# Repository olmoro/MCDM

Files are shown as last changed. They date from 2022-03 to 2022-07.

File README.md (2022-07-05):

### <p align="center">MCDM - Moro Charge and Discharge Module
***
#### <p align="center"> Как это работает.
Зарядное устройство состоит из трех блоков.
Первый из них блок питания на 18 вольт соответствующей мощности, например [WX-DC2406](https://aliexpress.ru/item/1005001714079538.html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) настроенный на выходное напряжение 18 вольт.

Второй блок - плата управления на микроконтроллере ESP-WROOM-32D - дисплей, кнопки, светодиодная индикация, USB интерфейс. Назначение - ввод-вывод пользовательских настроек, исполнение выбранного алгоритма работы, логирование и управление по каналу WiFi. Данные об этом блоке в своем депозитории.
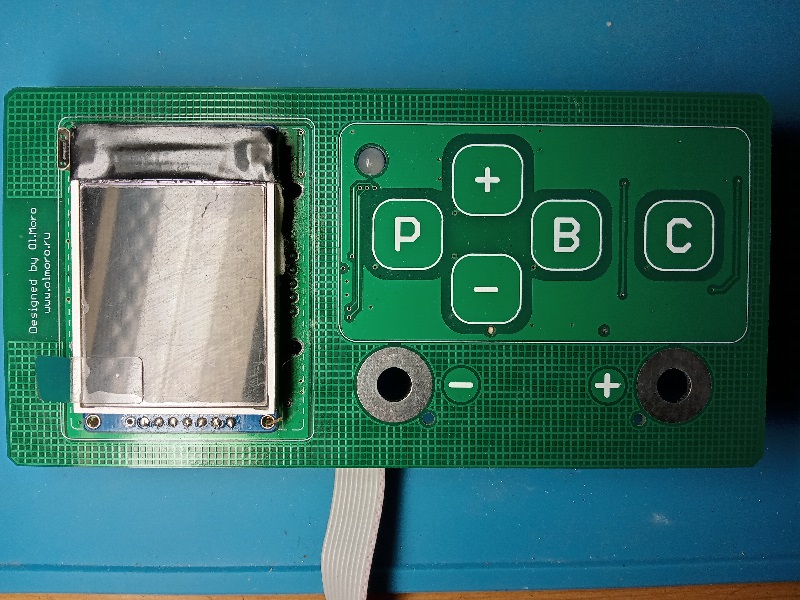
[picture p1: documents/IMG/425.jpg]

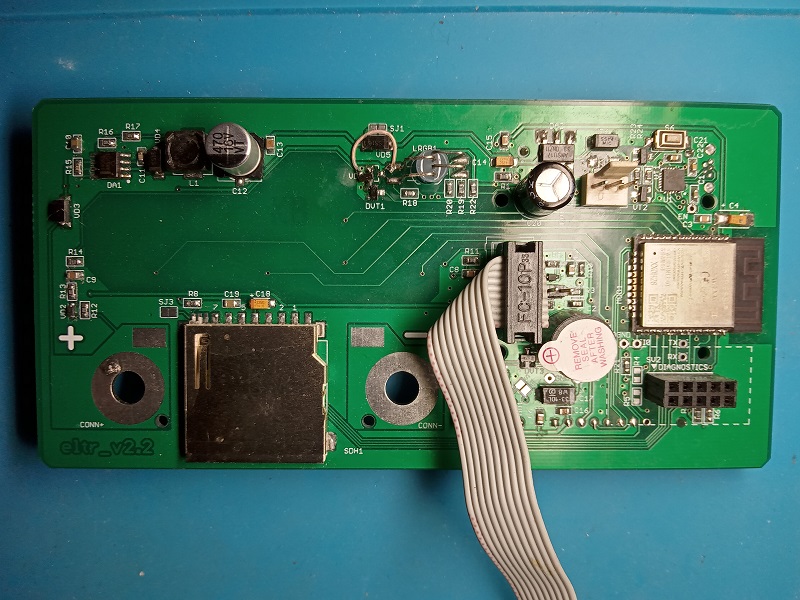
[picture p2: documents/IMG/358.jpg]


Третий блок - зарядно-разрядный модуль. Силовая часть заимствована от [XL4016 DC-DC Max 9A 300W](https://aliexpress.ru/item/32661166685.html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). Что от него осталось в итоге.
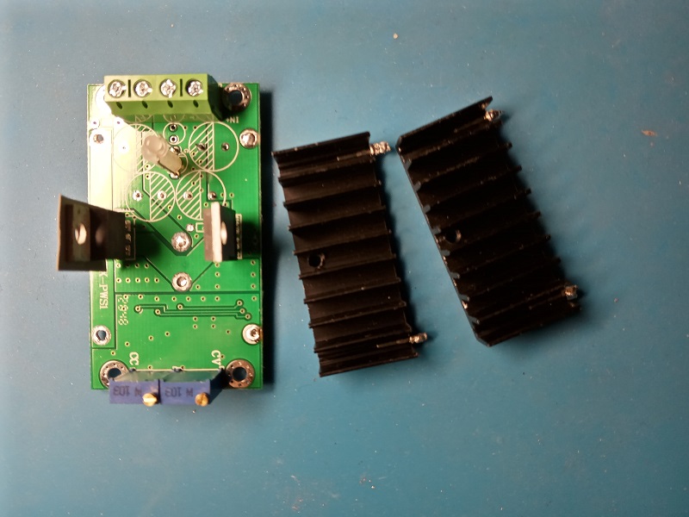
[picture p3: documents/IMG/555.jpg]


 Управляется субмодулем [WeMos D1 SAMD21 M0 Mini](https://aliexpress.ru/item/4001074203011.html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).
Субмодуль микроконтроллера съемный, устанавливается на гиперболические [разъемы](https://aliexpress.ru/item/32358969925.html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). Для работы с выходными ключами и питания субмодуля используются гальванически развязанные [источники](https://aliexpress.ru/item/1005003568781579.html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) мощностью 1 ватт. В свою очередь управляющие команды субмодуль получает по асинхронному интерфейсу от платы управления.
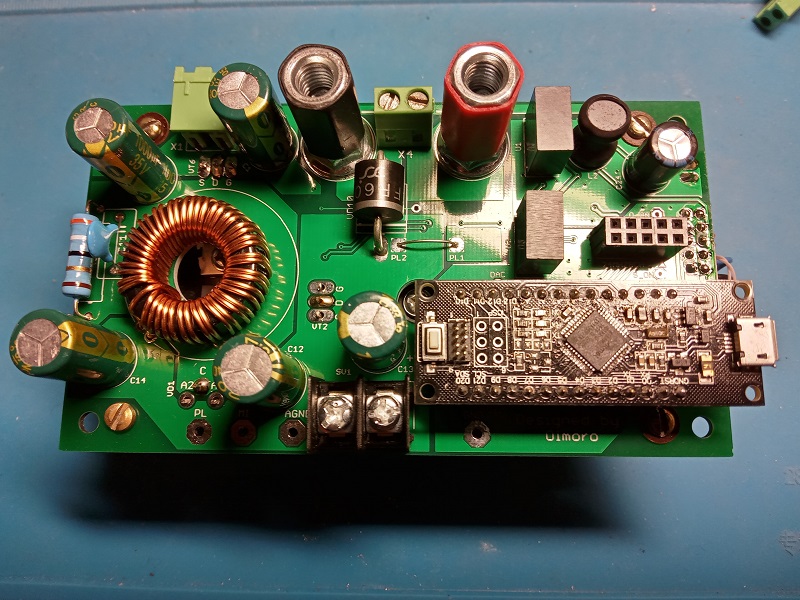
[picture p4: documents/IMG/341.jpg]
 Не отмыта пока.
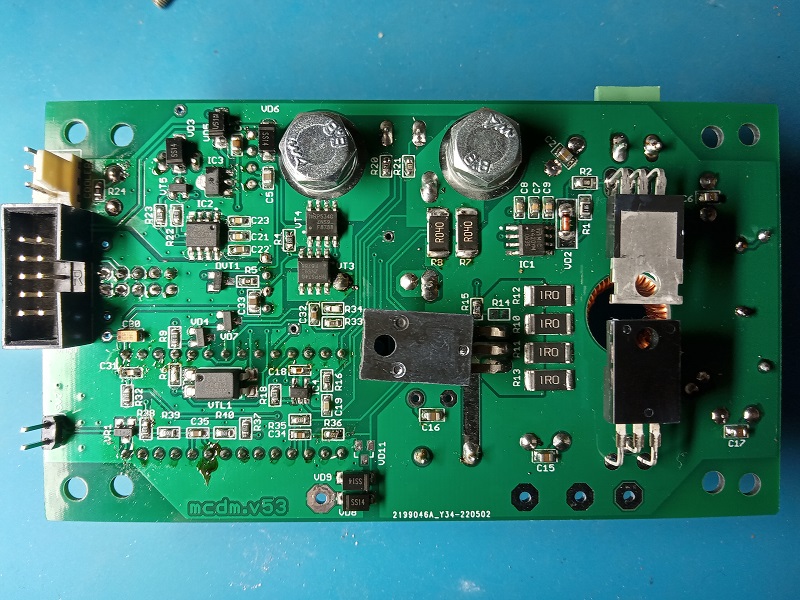
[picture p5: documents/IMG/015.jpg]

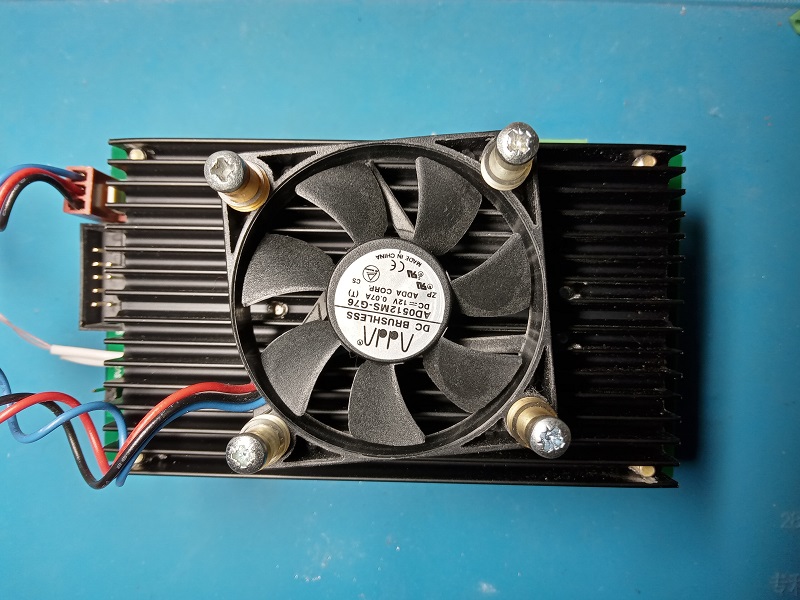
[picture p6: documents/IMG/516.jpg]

На блоке есть разъем для подключения 8-канального [логического анализатора](https://aliexpress.ru/item/4000183609972.html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).

#### <p align="center">Измерение напряжения
Измерение напряжения на подключенной батарее производятся по 4-х контактной схеме, используя дифференциальное измерение в диапазоне от -1.5 до 20 вольт. Погрешность измерения __% ± __ед.мзр.

#### <p align="center">Измерение токов заряда и разряда
Измерение токов заряда и разряда производится одним шунтом, используется сдвиг по напряжению для возможности измерения токов разной полярности в диапазоне от -5 до +10 ампер (ограничивается мощностью блока питания).  Погрешность измерения __% ± __ед.мзр.

#### <p align="center">Управление разрядной схемой
Ток разряда задается 10-разрядным встроенным ЦАП с поддержанием тока ПИД-регулятором. Схема разряда заимствована от Кулона 912, ток задается выходом DAC микроконтроллера. Внешним ОУ диапазон выходного сигнала расширен до 5 вольт. Для облегчения теплового режима регулирующего MOSFET предусмотрен разъем подключения внешней нагрузки.

#### <p align="center">Управление выходными ключами
Для реализации безискрового подключения заряжаемой батареи ключевой каскад управляется синхронно с силовым преобразователем, а именно: при отключении, например при перегрузке, одновременно отключается и силовой преобразователь. Остаточный заряд снимается подключением разрядной цепи (этот ток не проходит через токоизмерительный шунт). То есть включение преобразователя без подключения измерителя и на ХХ невозможно. Имеется возможность нагружать преобразователь при работе на холостом ходу или незначительной нагрузке.

#### <p align="center">Регулирование мощности DC преобразователя.
Управление понижающим преобразователем производится ШИМ-сигналом частотой 190кГц посредством MIC4420. Для регулирования напряжения и токов используются ПИД-регуляторы. В режиме заряда или источника питания регуляторы напряжения и тока используют собственные настройки. Для монотонности и непрерывности выходной характеристики используется один и тот же экземпляр регулятора. Принцип переключения от поддержания тока к поддержанию напряжения и обратно соответствует аналоговому регулятору 912-го кулона. Коэффициенты допускается регулировать "на лету". Для реализации импульсных режимов предусмотрены сохранение и восстановление параметров регулирования, но задание временнЫх параметров (длительность импульсов, например) возлагается на главный контроллер. Регулирование ведется с фиксированной частотой 10 Гц. Все вычисления целочисленные, так что вычисление шага занимает лишь несколько микросекунд. С этой целью параметры управления драйверу передаются предвычисленными и целочисленными.

#### <p align="center">Интерфейс
Обмен с главным контроллером производится по асинхронному каналу на частоте 115200 бод. Протокол обмена [WAKE](https://eewiki.ru/wiki/%D0%A1%D0%BF%D0%B5%D1%86%D0%B8%D1%84%D0%B8%D0%BA%D0%B0%D1%86%D0%B8%D1%8F_%D0%BF%D1%80%D0%BE%D1%82%D0%BE%D0%BA%D0%BE%D0%BB%D0%B0_WAKE) предусматривает проверку целостности пакета и подтверждение приема. Ведущим контроллером является главный контроллер, в фоновом режиме опрашивающий драйвер и получающий пакет, содержащий измерения напряжения в милливольтах и ток в миллиамперах, а также информацию о состоянии. Управляющими командами производится включение-отключение DC источника и задание напряжения и тока для ПИД-регулятора. Предусматривается достаточное количество команд настройки АЦП, приборного смещения, калибровочных коэффициентов для  преобразования в физические величины, порогов срабатывания защиты и т.д. Для управления и настройки ПИД-регулятора, и ещё масса тестовых команд, надобность в которых практически отпала по ходу дела. Заводские и пользовательские установки хранятся в памяти управляющего контроллера и загружаться на этапе инициализации, заменяя параметры разработчика (defaults).

В директории Frames представлены данные для тестирования с помощью приложения WakeUsb.

#### <p align="center">Система охлаждения
Силовые элементы, [датчик температуры](https://aliexpress.ru/item/33014111002.html?spm=a2g2w.productlist.0.0.108e2a96XiZTKA&sku_id=67175460751) и [вентилятор](https://aliexpress.ru/item/4001029238958.html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) размещены на [радиаторе](https://aliexpress.ru/item/1005003036398261.html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) размером 100x60x10 мм. Регулирование производится ПИД-регулятором.

#### <p align="center">Печатная плата
115*65 мм двусторонняя 1oz. Схема, сборки, перечень элементов и гербер-файлы в директории Docements.

#### <p align="center">Формат реализованных команд управления.
##### <p align="center">(Не отредактировано)
Имя | Код | Параметр | Ответ | Примечание
--------------------------:|------:|-------:|-------------:|----------------------------------:
cmd_read_u_i|0x10|-|int int uint|Чтение напряжения,тока (мВ и мА) и состояния
cmd_get_u|0x11|-|int|Чтение напряжения (мВ)
cmd_get_i|0x12|-|int|Чтение тока (мА)
cmd_get_ui|0x13|-|int int|Чтение напряжения и тока (мВ и мА)
cmd_get_state|0x14|-|uint|Чтение состояния
cmd_get_state|0x15|-|uint|Чтение температуры радиатора
cmd_power_go|0x20|-|-|Старт преобразователя с заданными максимальными U и I
cmd_power_stop|0x21|-|-|Отключение ( и разряда в том числе)
cmd_set_pid|0x22|-|-|set all parameters (в разработке)
cmd_get_factor_u|0x30|-|uint|Чтение множителя преобразования в милливольты
cmd_set_factor_u|0x31|uint|-|Запись множителя преобразования в милливольты
cmd_set_factor_default_u|0x32|-|-|Возврат к заводскому множителю преобразования в милливольты
cmd_get_smooth_u|0x33|-|uint|Чтение параметра сглаживания по напряжению
cmd_set_smooth_u|0x34|uint|-|Запись параметра сглаживания по напряжению (1...3)
cmd_get_offset_u|0x35|-|uint|Чтение приборного смещения по напряжению
cmd_set_offset_u|0x36|int|-|Запись приборного смещения по напряжению
cmd_get_factor_i|0x38|-|uint|Чтение множителя преобразования в миллиамперы
cmd_set_factor_i|0x39|uint|-|Запись множителя преобразования в миллиамперы
cmd_set_factor_default_i|0x3A|-|-|Возврат к заводскому множителю преобразования в миллиамперы
cmd_get_smooth_i|0x3B|-|uint|Чтение параметра сглаживания по току
cmd_set_smooth_i|0x3C|uint|-|Запись параметра сглаживания по току (1...3)
cmd_get_offset_i|0x3D|-|uint|Чтение приборного смещения по току
cmd_set_offset_i|0x3E|int|-|Запись приборного смещения по току
cmd_pid_configure|0x40|uint uint uint uint uint uint|-|set mode,kp,ki,kd,min,max
cmd_pid_set_coefficients|0x41|uint uint uint|-|set kp, ki, kd
cmd_pid_output_range|0x42|uint uint|-|set min, max
cmd_pid_reconfigure|0x43|uint uint uint uint uint|-|set kp,ki,kd,min,max w/o clear
cmd_pid_clear|0x44|-|-|clear
cmd_pid_test|0x46|uint uint uint|-|mode, setpoint, sw
cmd_pid_get_configure|0x48|-|uint uint uint uint uint uint|mode,kP,kI,kD,min,max - возвращает параметры текущего режима регулирования
cmd_pid_set_max_sum|0x49|uint|-|Задает максимальный интеграл при вычислении шага рег.
cmd_set_cooler|0x4F|uint|-|Задать скорость вентилятора
cmd_adc_read_probes|0x50|-|int,int|Read all probes
cmd_adc_get_offset|0x51|-|int|Читать смещение АЦП
cmd_adc_set_offset|0x52|int|-|Запись смещения АЦП
cmd_set_switch_pin|0x54|?|-|sw_pin D4 PA14 ?
cmd_set_power|0x56|int|-|пользоваться с осторожностью - выяснение пределов регулирования
cmd_set_discharge|0x57|uint|-|не проверена
cmd_set_voltage|0x58|uint|-|старая, не проверена
cmd_set_current|0x59|uint|-|старая, не проверена
cmd_set_discurrent|0x5A|uint|-|старая, не проверена
cmd_set_surge_compensation|0x5B|?|-|параметры подавления всплеска напряжения na
cmd_set_idle_load|0x5C|uint|-|параметры доп.нагрузки ХХ
cmd_get_win_less_u|0x60|-|int|Порог отключения по Umin
cmd_set_win_less_u|0x61|int|-|Порог отключения по Umin
cmd_set_win_less_default_u|0x62|int|-|Порог отключения по Umin
cmd_get_win_up_u|0x63|-|int|Порог отключения по Umax
cmd_set_win_up_u|0x64|int|-|Порог отключения по Umax
cmd_set_win_up_default_u|0x65|int|-|Порог отключения по Umax
cmd_get_win_less_i|0x68|-|int|Порог отключения по Imin
cmd_set_win_less_i|0x69|int|-|Порог отключения по Imin
cmd_set_win_less_default_i|0x6A|int|-|Порог отключения по Imin
cmd_get_win_up_i|0x6B|-|int|Порог отключения по Imax
cmd_set_win_up_i|0x6C|int|-|Порог отключения по Imax  
cmd_set_win_up_default_i|0x6D|int|-|Порог отключения по Imax

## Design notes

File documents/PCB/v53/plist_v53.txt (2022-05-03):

Partlist

Exported from mcdm.v53.sch at 03.05.2022 9:25

EAGLE Version 7.3.0 Copyright (c) 1988-2015 CadSoft

Assembly variant: 

Part     Value          Device              Package       Library              Sheet

+5V                     WIREPAD1,6/0,8      1,6/0,8       wirepad              2
+18V                    WIREPAD1,6/0,8      1,6/0,8       wirepad              1
AGND     AGND           WIREPAD4,16O1,6     4,16O1,6      wirepad              2
C1       1000µF 35v     CPOL-EUE5-10.5      E5-10,5       rcl_moro             1
C2       100n           C-EUC0805           C0805         rcl_moro             1
C3       1000µF 35v     CPOL-EUE5-10.5      E5-10,5       rcl_moro             1
C4       4.7µF          C-EUC0603           C0603         rcl_moro             1
C5       4.7µF          C-EUC0603           C0603         rcl_moro             1
C6       100n           C-EUC0805           C0805         rcl_moro             1
C7       100n           C-EUC0603           C0603         rcl_moro             1
C8       1mkF           C-EUC0603           C0603         rcl_moro             1
C9       100n           C-EUC0603           C0603         rcl_moro             1
C11      4.7nF 1KV      C-EU102-064X133     C102-064X133  rcl_moro             1
C12      470µF 35v      CPOL-EUE5-10.5      E5-10,5       rcl_moro             1
C13      na             CPOL-EUE5-10.5      E5-10,5       rcl_moro             1
C14      470µF 35v      CPOL-EUE5-10.5      E5-10,5       rcl_moro             1
C15      1mkF           C-EUC0805           C0805         rcl_moro             1
C16      1mkF           C-EUC0805           C0805         rcl_moro             1
C17      1mkF           C-EUC0805           C0805         rcl_moro             1
C18      100nF X7R      C-EUC0603           C0603         rcl_moro             1
C19      1µF            C-EUC0603           C0603         rcl_moro             1
C21      100n           C-EUC0603           C0603         rcl_moro             1
C22      1mkF           C-EUC0603           C0603         rcl_moro             1
C23      100n           C-EUC0603           C0603         rcl_moro             1
C24      220uF 25v      CPOL-EUE5-8.5       E5-8,5        rcl_moro             1
C30      4.7µF          C-EUC0805           C0805         rcl_moro             2
C31      100nF X7R      C-EUC0603           C0603         rcl_moro             2
C32      470n           C-EUC0603           C0603         rcl_moro             2
C33      3.3µF          C-EUC0805           C0805         rcl_moro             2
C34      470nF          C-EUC0603           C0603         rcl_moro             2
C35      470nF          C-EUC0603           C0603         rcl_moro             2
COOLER   WF-3 (WF-2)    WF-3                WF-3          moro2                1
DAC                     WIREPAD1,6/0,8      1,6/0,8       wirepad              2
DVT1     PDTA123ET      MUN2113T1           SC59-BEC      transistor-pnp       1
GND      GND            WIREPAD4,16O1,6     4,16O1,6      wirepad              2
IC1      MIC4420M       MIC4420M            SO-08         transistor-power     1
IC2      MIC4420M       MIC4420M            SO-08         transistor-power     1
IC3      78L12F         78L12F              SOT89         linear               1
IC4      LMV321(MCP601) LM321MF             SOT23-5       linear               1
L1       L32MM          L32MM               L22MM         wx-d21               1
L2       560uH          BS11                BS11          inductor-neosid-moro 1
MI                      WIREPAD4,16O1,6     4,16O1,6      wirepad              1
OUT                     WIREPAD1,6/0,8      1,6/0,8       wirepad              2
O_ON                    WIREPAD1,6/0,8      1,6/0,8       wirepad              2
PL                      WIREPAD4,16O1,6     4,16O1,6      wirepad              1
PL1                     WIREPAD2,54/0,8     2,54/0,8      wirepad              1
PL2                     WIREPAD2,54/0,8     2,54/0,8      wirepad              1
R1       5R1            R-EU_R0805          R0805         rcl_moro             1
R2       1R             R-EU_R0805          R0805         rcl_moro             1
R3       39 Om 5%       R-0515/20           0515/20       Q921                 1
R4       2.2k           R-EU_R0603          R0603         rcl_moro             1
R5       330            R-EU_R0603          R0603         rcl_moro             1
R6       680            R-EU_R0603          R0603         rcl_moro             1
R7       R04            R-EU_R2512          R2512         rcl_moro             1
R8       R04            R-EU_R2512          R2512         rcl_moro             1
R9       100k           R-EU_R0603          R0603         rcl_moro             1
R10      1R0            R-EU_R2512          R2512         rcl_moro             1
R11      1R0            R-EU_R2512          R2512         rcl_moro             1
R12      1R0            R-EU_R2512          R2512         rcl_moro             1
R13      1R0            R-EU_R2512          R2512         rcl_moro             1
R14      na             R-EU_R0603          R0603         rcl_moro             1
R15      5k1            R-EU_R0603          R0603         rcl_moro             1
R16      5k1            R-EU_R0603          R0603         rcl_moro             1
R18      5k1            R-EU_R0603          R0603         rcl_moro             1
R20      22R            R-EU_R0603          R0603         rcl_moro             1
R21      22R            R-EU_R0603          R0603         rcl_moro             1
R22      100k           R-EU_R0603          R0603         rcl_moro             1
R23      51             R-EU_R0603          R0603         rcl_moro             1
R24      10k            R-EU_R0603          R0603         rcl_moro             1
R32      680            R-EU_R0603          R0603         rcl_moro             2
R33      39k0           R-EU_R0603          R0603         rcl_moro             2
R34      4k70           R-EU_R0603          R0603         rcl_moro             2
R35      22             R-EU_R0603          R0603         rcl_moro             2
R36      22             R-EU_R0603          R0603         rcl_moro             2
R37      4k7            R-EU_R0603          R0603         rcl_moro             2
R38      10k0           R-EU_R0603          R0603         rcl_moro             2
R39      30k            R-EU_R0603          R0603         rcl_moro             2
R40      30k            R-EU_R0603          R0603         rcl_moro             2
SV1      TB-10-2        TB-10-2             TB-10-2       wx-d21               1
SV2                     JP1Q                JP1           jumper_moro          2
SV4      FE05-2R        FE05-2R             FE05-2R       con-lsta_moro        2
S_ON                    WIREPAD1,6/0,8      1,6/0,8       wirepad              2
U1       HLK-1D1212     HLK-1D1212          HLK-1D1212    wx-d21               1
U2       B1205S-1W      HLK-1D1212          HLK-1D1212    wx-d21               2
UART     BH-10          ML10                ML10          con-harting-ml       2
VD1      MBR20100F      MBR20100F           ITO220J       wx-d21               1
VD2      4148           DIODESMA            SMADIODE      microbuilder         1
VD3      SS16           SS16                DO214AC       diode-1              1
VD4      BAT54S         BAT54S              SOT23         diode                2
VD5      US1M           US1M                DO214AC       diode-1              1
VD6      SS16           SS16                DO214AC       diode-1              1
VD7      BAT54S         BAT54S              SOT23         diode                2
VD8      SS16           SS16                DO214AC       diode-1              2
VD9      SS16           SS16                DO214AC       diode-1              2
VD10     FR601          DIODE-1_DIODE-P6-15 DIODE-1_P6-15 urc-2base            1
VD11     BAT54S         BAT54S              SOT23         diode                2
VR1      TL431          TL431-SOT23-3       SOT23         moro4                2
VT2      STP16NF06FP    STP16NF06FP         TO-220FP_M    wx-d21               1
VT3      IRF8788        IRF8788             SO-8          transistor-fet_moro  1
VT4      IRF8788        IRF8788             SO-8          transistor-fet_moro  1
VT5      IRLML5203      IRLML5203           MICRO3        transistor-power     1
VT6      IRFP9540N_M    IRFP9540N_M         TO-220FP_M    wx-d21               1
VTL1     K10104C        SFH618A-3X007       SMD4-7        optocoupler          1
X1       MSTBA2         MSTBA2              MSTBA2        con-phoenix-508      1
X2       BP-R           BP-R                BP-R          wx-d21               1
X3       BP-B           BP-B                BP-B          wx-d21               1
X4                      AK500/2-H           AK500/2-H     con-ptr500_moro      1
X5       F14GIP         F14GIP              F14GIP        wx-d21               2
X6       F14GIP         F14GIP              F14GIP        wx-d21               2

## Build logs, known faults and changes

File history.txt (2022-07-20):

.LOG

20:02 04.12.2021
После переустановки VS на Lenovo
MSAMD21 - полная копия MORO_D21 (DRV_BS4) MORO_D21_20210515full.zip - архив полный
Папка проекта F:\GitHub

14:57 09.12.2021
Добавлено
documents (Frames, Pid)

20:26 26.01.2022
Проект скопирован под новым именем MCDM: Измерительный модуль ЗУ с теплоотводом (Charge and discharge module)
Размер платы 100 * 65 мм.
Питание от внешнего источника 18 вольт 6 ампер.
Подключение батареи четырехточечное.
Интерфейс асинхронный 115200 Бод.
Выходной ток заряда до 10 ампер (измеряемый).
Входной ток заряда до 10 ампер (измеряемый).
Измерение выходного напряжения от -2 до 18 вольт.
Измерение тока от -10 до +10 ампер одним шунтом.
Пид-регулирование.

Будет добавлено управление системой охлаждения.

https://github.com/ocrdu/Arduino_SAMD21_turbo_PWM
  PWM Freg 192.0 kHz:
Main Clock Divider  1   5
TCCx Prescaler      1   1
Resolution          500 100

SAMD21G18 timer/channel:

TCC0/WO[0]: PA04, PA08         TCC0/WO[4]: PA14, PA22, PB10
TCC0/WO[1]: PA05, PA09         TCC0/WO[5]: PA15, PA23, PB11
TCC0/WO[2]: PA10, PA18         TCC0/WO[6]: PA12, PA16, PA20
TCC0/WO[3]: PA11, PA19         TCC0/WO[7]: PA13, PA17, PA21

TCC1/WO[0]: PA06, PA10, PA30   TCC1/WO[2]: PA08, PA24
TCC1/WO[1]: PA07, PA11, PA31   TCC1/WO[3]: PA09, PA25

TCC2/WO[0]: PA00, PA12, PA16
TCC2/WO[1]: PA01, PA13, PA17

20:26 07.03.2022
Для совместимости с SAMD21turboPWM.h
изменена схема подключения cool_pin и out_pin
TCC0/WO[2]: PA18(out)
TCC2/WO[0]: PA16(cool)

13:26 21.04.2022
Заменить эти файлы на одноименные из "documents/Variant"
C:\Users\olmor\.platformio\packages\framework-arduino-samd\variants\arduino_zero\variant.cpp
C:\Users\olmor\.platformio\packages\framework-arduino-samd\variants\arduino_zero\variant.h
C:\Users\olmor\.platformio\packages\framework-arduino-samd\cores\arduino\wiring_analog.c

9:29 03.05.2022
Заказано изготовление mcdm_v53
19:29 22.05.2022
маркировка R33, R34 переставлена. Откорректировано в v53a.
Добавлены резисторы защиты по 7,5кОм
19:50 28.05.2022
Увеличена скорость обмена до 230400
10:29 03.07.2022
Версия 0.1 с пид-регуляторами

// param_shift увеличен с 8 до 12; param_max = 0x000F, param_mult = 0x1000
RAM:   [=         ]  12.7% (used 4176 bytes from 32768 bytes)
Flash: [=         ]   9.2% (used 24228 bytes from 262144 bytes)

04.07.2022
Новые модули на COM13 и COM14 (Arduino Zero 1.4.3.0) проверены

05.07.2022
Отказ от эмуляции EEPROM. Заводские и пользовательские установки
будут храниться в памяти управляющего контроллера и загружаться
на этапе инициализации, заменяя параметры разработчика (defaults) 
RAM:   [=         ]   9.5% (used 3120 bytes from 32768 bytes)
Flash: [=         ]   8.7% (used 22692 bytes from 262144 bytes)

14.07
COM14 - OK
RAM:   [=         ]   9.5% (used 3120 bytes from 32768 bytes)
Flash: [=         ]   8.7% (used 22720 bytes from 262144 bytes)

19.07
Новая команда 0x47 отдает paramMult
RAM:   [=         ]   9.5% (used 3120 bytes from 32768 bytes)
Flash: [=         ]   8.7% (used 22784 bytes from 262144 bytes)

20.07
RAM:   [=         ]   9.5% (used 3120 bytes from 32768 bytes)
Flash: [=         ]   8.7% (used 22780 bytes from 262144 bytes)

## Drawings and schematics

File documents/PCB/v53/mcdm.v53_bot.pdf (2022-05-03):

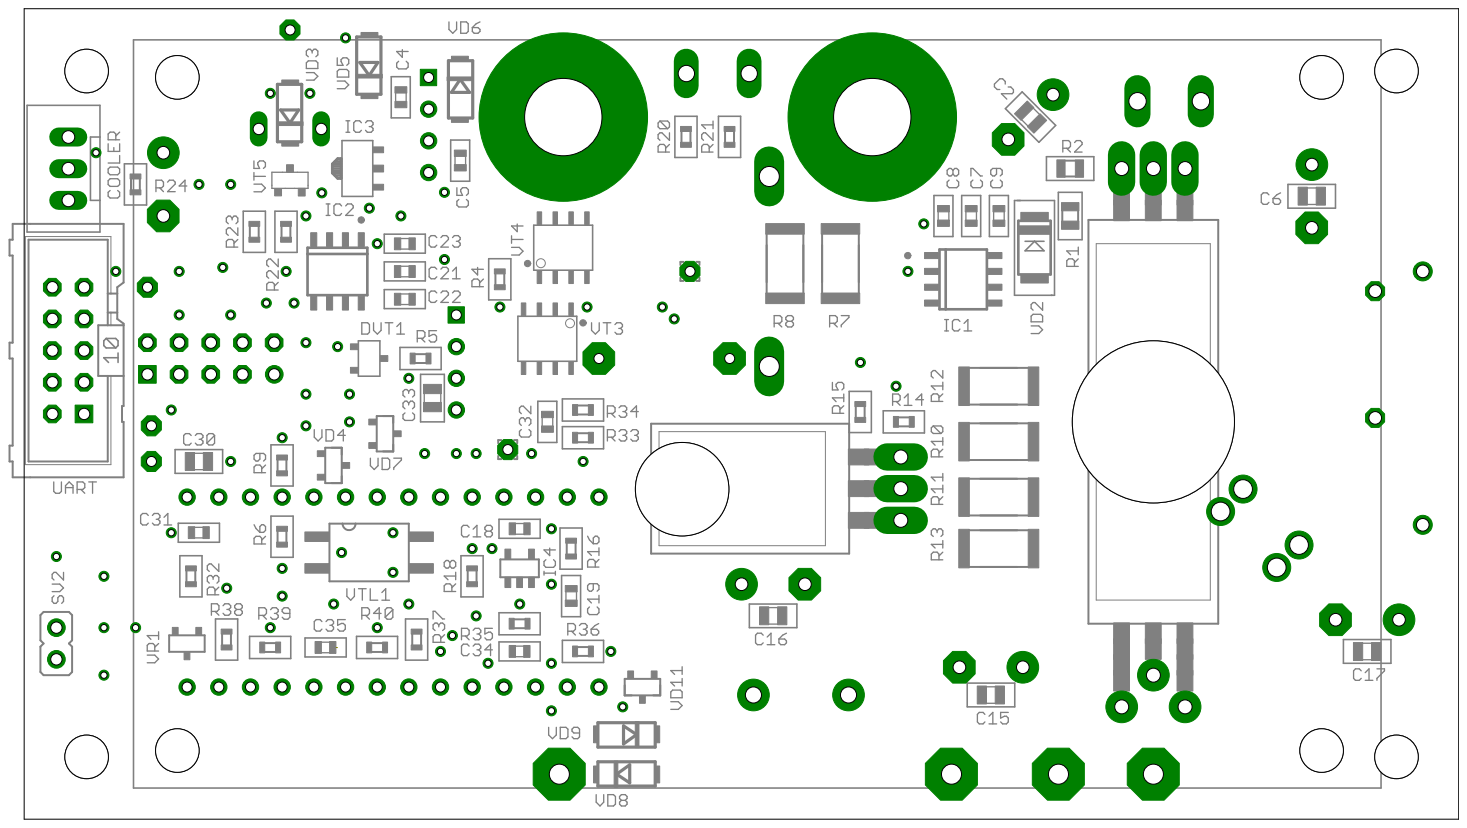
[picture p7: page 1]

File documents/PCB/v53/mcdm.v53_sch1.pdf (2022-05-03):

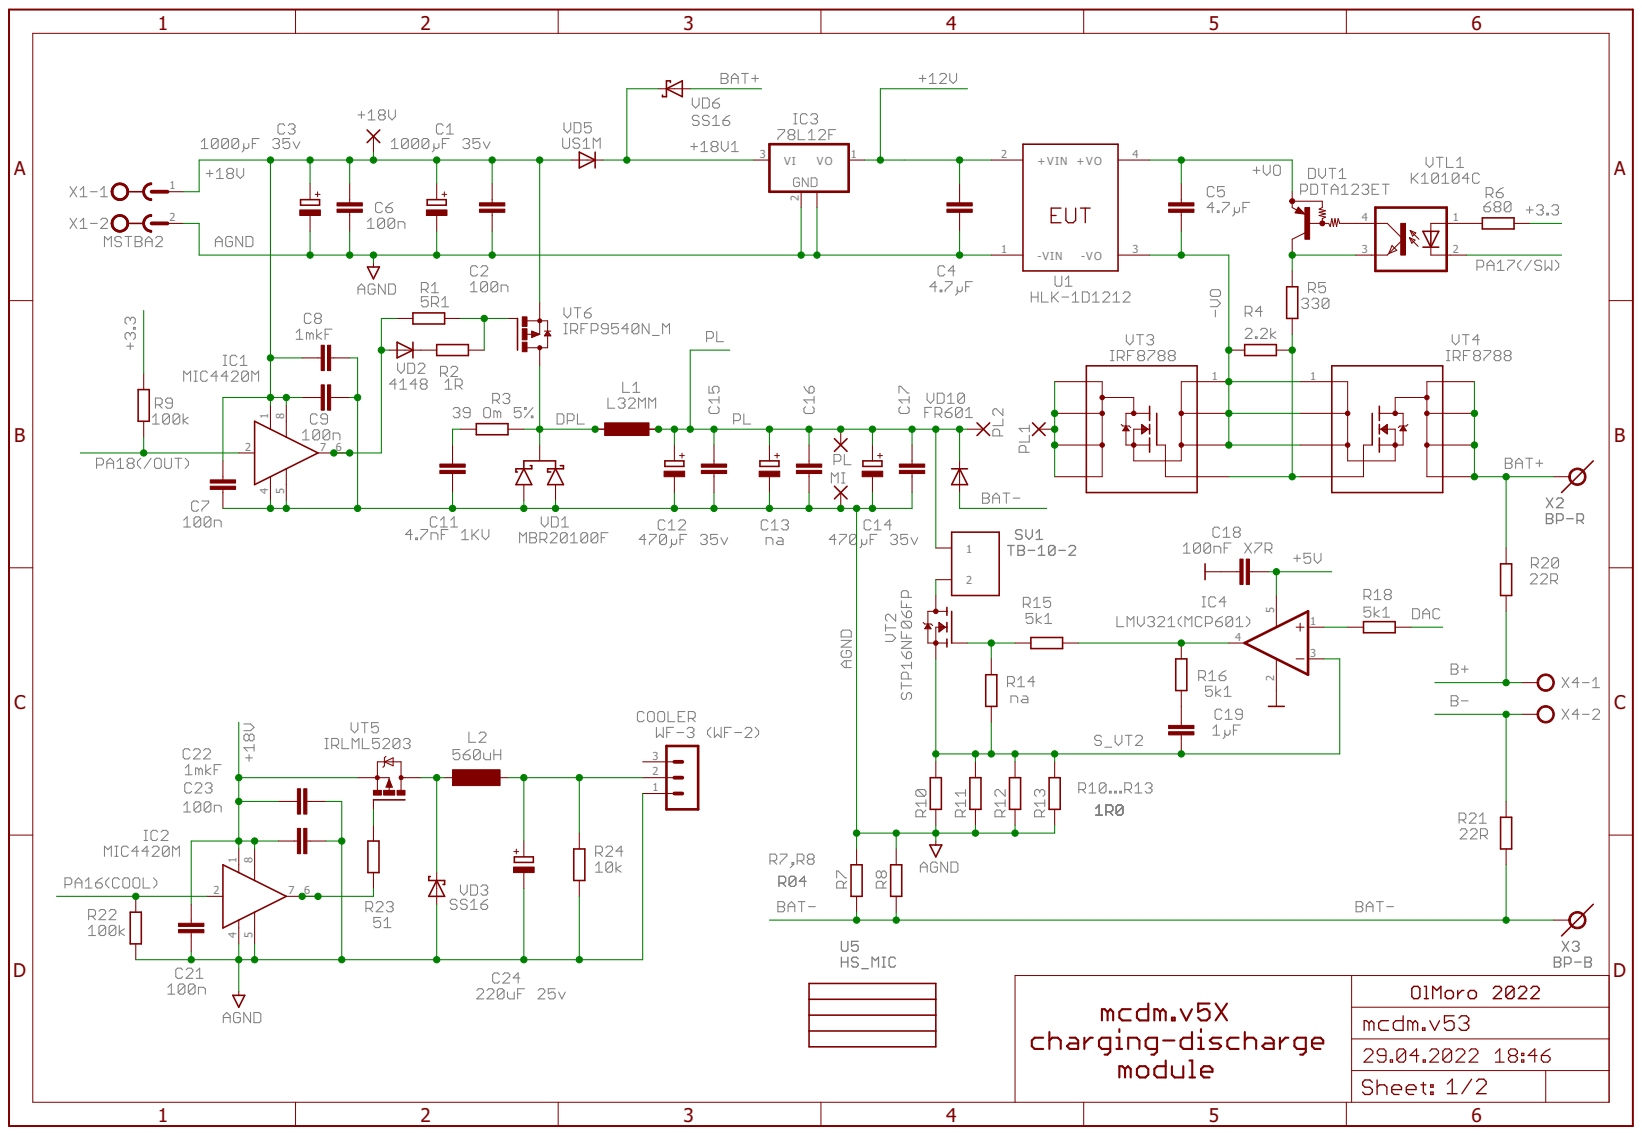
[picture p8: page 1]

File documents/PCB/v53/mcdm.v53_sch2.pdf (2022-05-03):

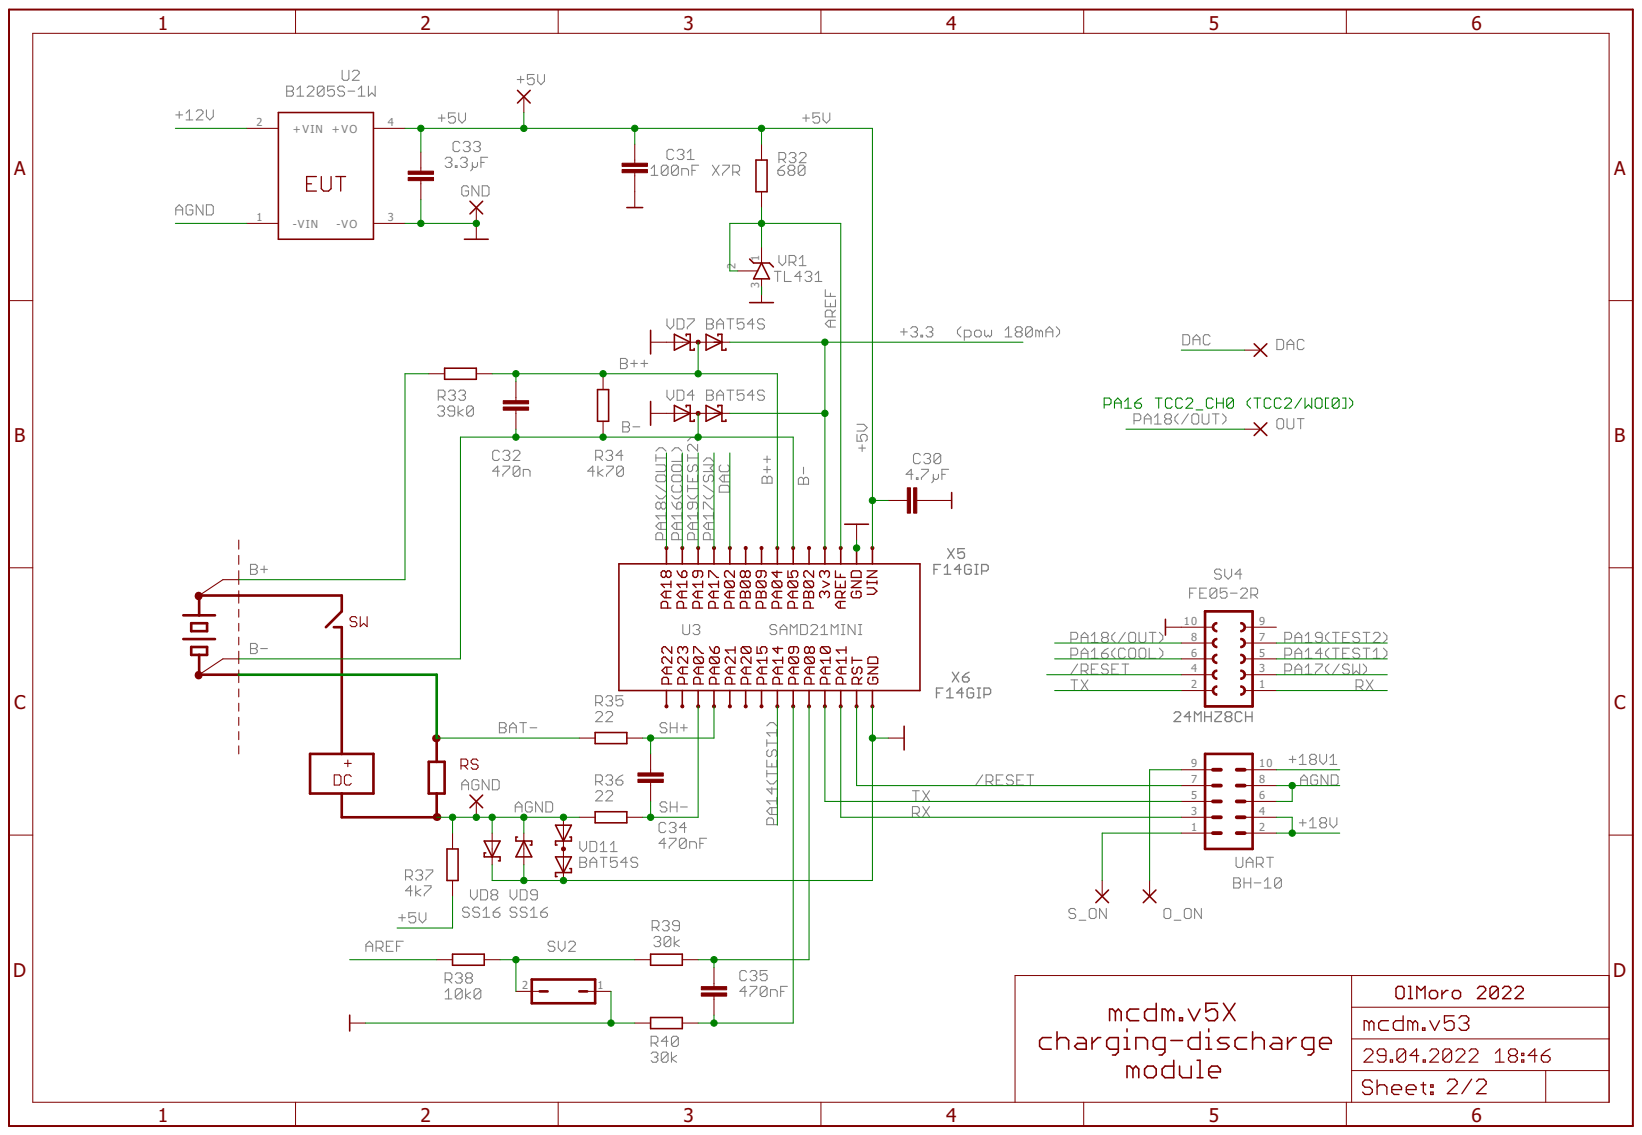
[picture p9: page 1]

1 2 3 975 1086 31 421 2 3 4 5 6 7 8 9 10 -VIN 1 +VIN 2 +VO 4 -VO 3 2 1 ABCD 1 2 3 4 5 6 ABCD 1 2 3 4 5 6

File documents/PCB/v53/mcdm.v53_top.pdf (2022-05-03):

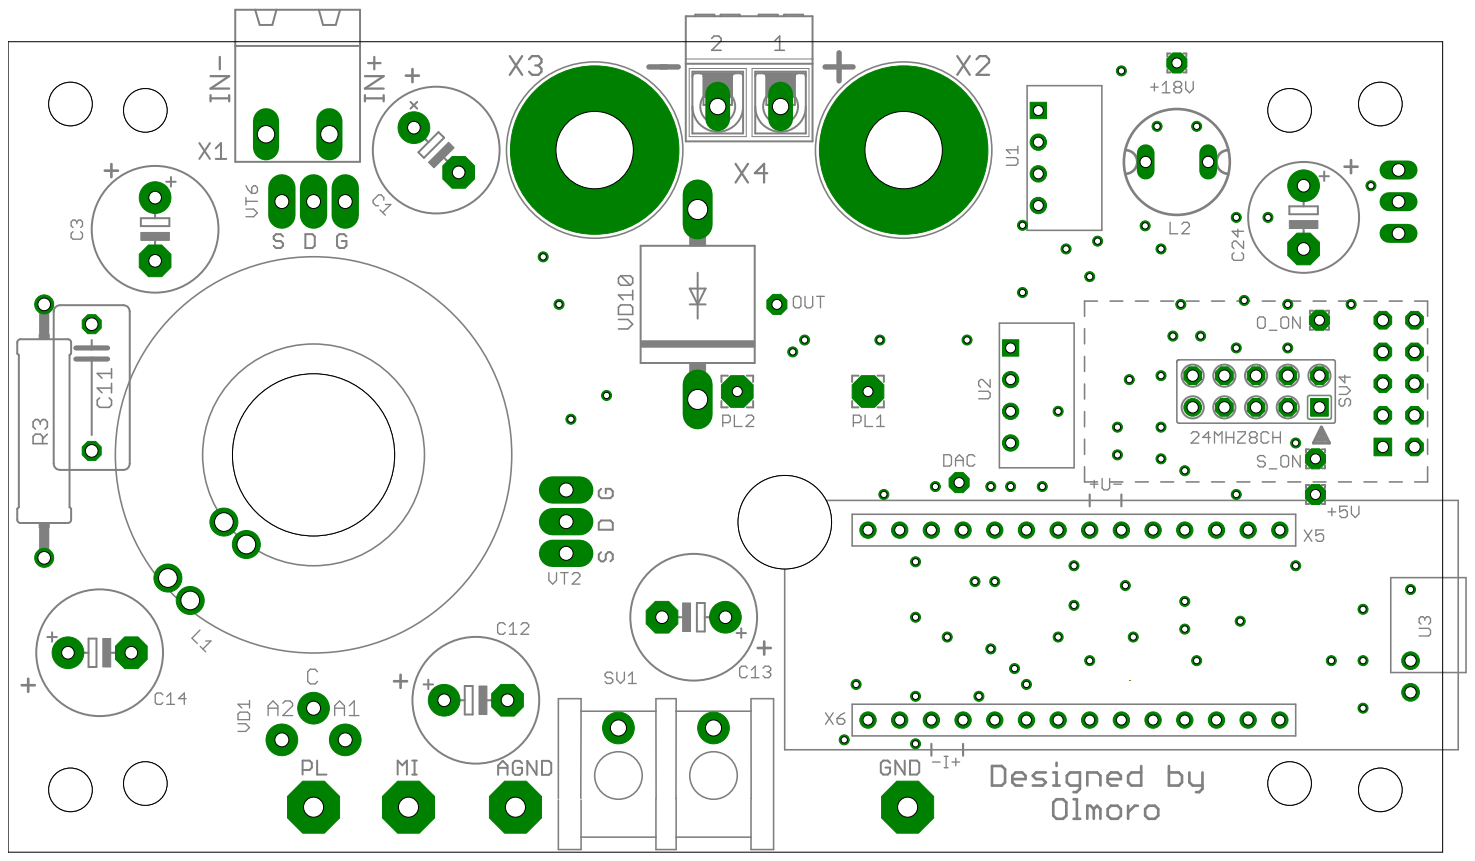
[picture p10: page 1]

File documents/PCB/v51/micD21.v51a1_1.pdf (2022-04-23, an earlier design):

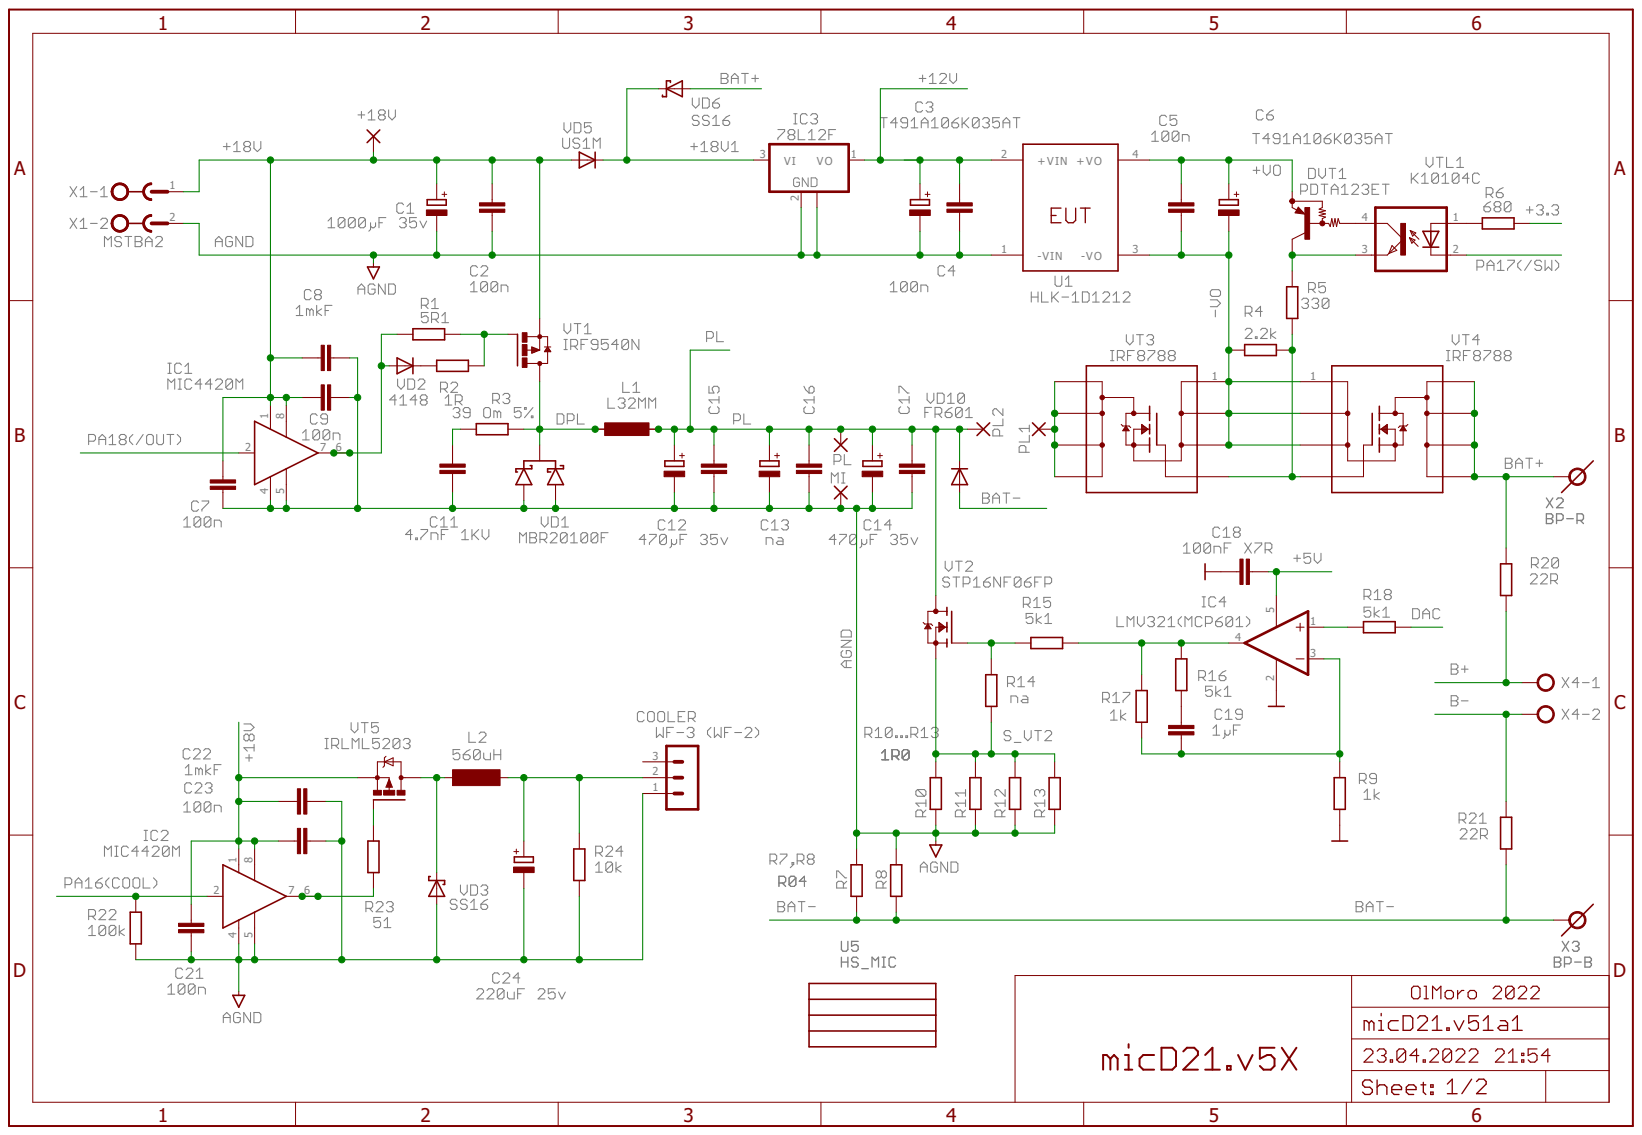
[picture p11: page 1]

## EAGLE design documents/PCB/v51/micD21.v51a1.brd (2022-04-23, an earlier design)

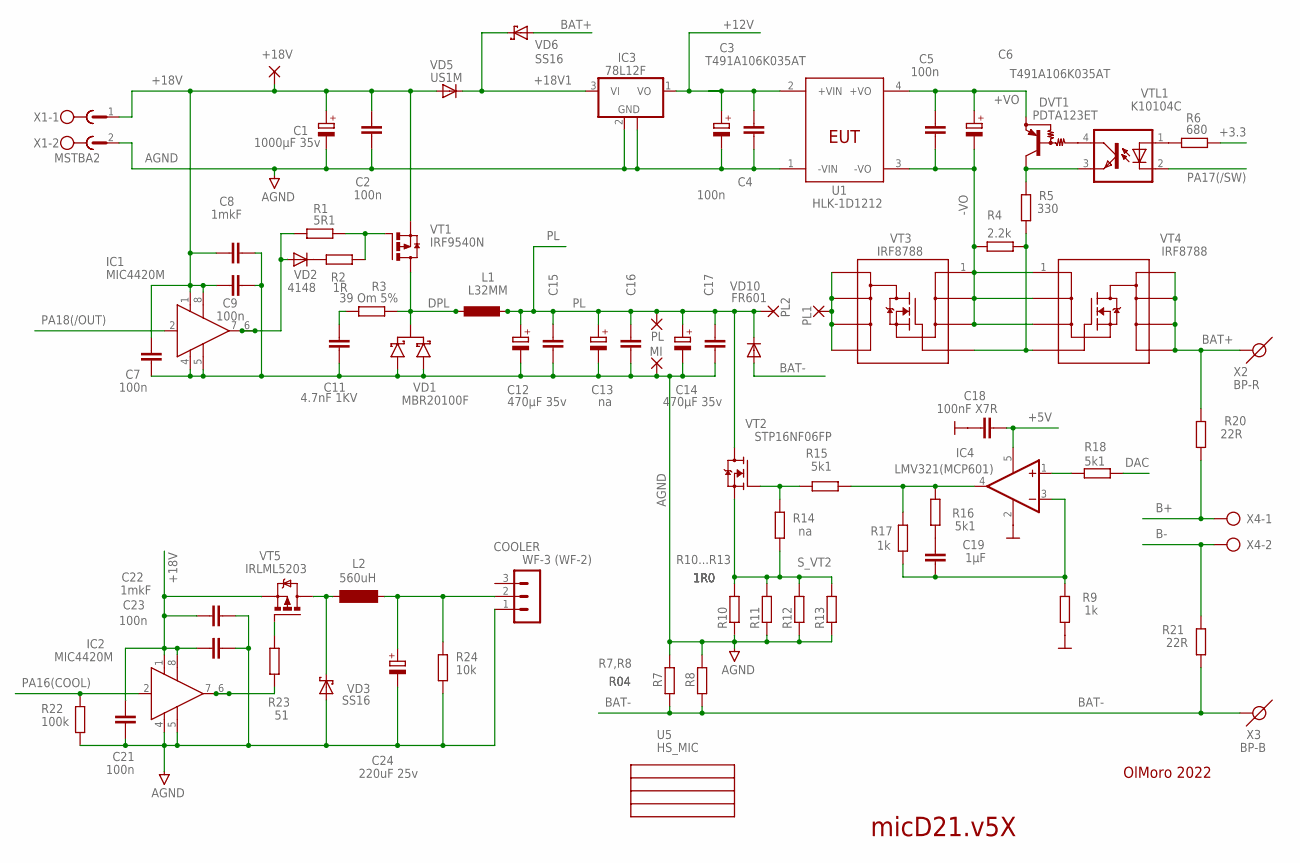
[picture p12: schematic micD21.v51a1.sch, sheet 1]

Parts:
+18V: WIREPAD1,6/0,8; 1,6/0,8
C1: 1000µF 35v; E5-10,5
C2: 100n; C0805
C3, C6: T491A106K035AT; CT3528
C4, C5, C7, C9, C21, C23: 100n; C0603
C8, C22: 1mkF; C0603
C11: 4.7nF 1KV; C102-064X133
C12, C14: 470µF 35v; E5-10,5
C13: na; E5-13
C15, C16, C17: 1mkF; C0805
C18: 100nF X7R; C0603
C19: 1µF; C0603
C24: 220uF 25v; E5-8,5
COOLER: WF-3 (WF-2); WF-3
DVT1: PDTA123ET; SC59-BEC
IC1, IC2: MIC4420M; SO-08
IC3: 78L12F; SOT89
IC4: LMV321(MCP601); SOT23-5
L1: L32MM; L22MM
L2: 560uH; BS11
MI: 4,16O1,6
PL: 4,16O1,6
PL1, PL2: 2,54/0,8
R1: 5R1; R0805
R2: 1R; R0805
R3: 39 Om 5%; 0515/20
R4: 2.2k; R0603
R5: 330; R0603
R6: 680; R0603
R7, R8: R04; R2512
R9, R17: 1k; R0603
R10, R11, R12, R13: 1R0; R2512
R14: na; R0603
R15, R16, R18: 5k1; R0603
R20, R21: 22R; R0603
R22: 100k; R0603
R23: 51; R0603
R24: 10k; R0603
U1: HLK-1D1212
U5: HS_MIC; HS-MIC
VD1: MBR20100F; ITO220J
VD2: 4148; SMADIODE
VD3, VD6: SS16; DO214AC
VD5: US1M; DO214AC
VD10: FR601; DIODE-1_P6-15
VT1: IRF9540N; TO-220FP
VT2: STP16NF06FP; TO-220FP
VT3, VT4: IRF8788; SO-8
VT5: IRLML5203; MICRO3
VTL1: K10104C; SMD4-7
X1: MSTBA2
X2: BP-R
X3: BP-B
X4: AK500/2-H

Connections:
+3.3: R6.1; also elsewhere on the board
+5V: C18.2, IC4.5 (V+); also elsewhere on the board
+12V: C3.+, C4.2, IC3.1 (VO), U1.2 (+VIN); also elsewhere on the board
+18V: +18V.1, C1.+, C2.2, C7.2, C8.2, C9.2, C21.2, C22.2, C23.2, IC1.1 (VS), IC1.8 (VS1), IC2.1 (VS), IC2.8 (VS1), VD5.A, VT1.3 (S), VT5.2 (S), X1.1; also elsewhere on the board
+18V1: IC3.3 (VI), VD5.C, VD6.C; also elsewhere on the board
+VO: C5.2, C6.+, DVT1.E, U1.4 (+VO)
-VO: C5.1, C6.-, R4.2, U1.3 (-VO), VT3.1 (S), VT3.2 (S), VT3.3 (S), VT4.1 (S), VT4.2 (S), VT4.3 (S)
AGND: C1.-, C2.1, C3.-, C4.1, C7.1, C8.1, C9.1, C11.2, C12.-, C13.-, C14.-, C15.2, C16.2, C17.2, C21.1, C22.1, C23.1, C24.-, COOLER.1, IC1.4 (GND), IC1.5 (GND1), IC2.4 (GND), IC2.5 (GND1), IC3.2 (GND), IC3.2@1 (GND), MI.1, R7.2, R8.2, R10.1, R11.1, R12.1, R13.1, R22.2, R24.2, U1.1 (-VIN), VD1.1 (A1), VD1.3 (A2), VD3.A, X1.2; also elsewhere on the board
B+: R20.1, X4.1; also elsewhere on the board
B-: R21.1, X4.2; also elsewhere on the board
BAT+: R20.2, VD6.A, VT4.5 (D), VT4.6 (D), VT4.7 (D), VT4.8 (D), X2.1
BAT-: R7.1, R8.1, R21.2, VD10.A, X3.1; also elsewhere on the board
DAC: R18.2; also elsewhere on the board
DPL: L1.2@7 (2), L1.2@8 (2), R3.1, VD1.2 (C), VT1.2 (D)
G: R4.1, R5.1, VT3.4 (G), VT4.4 (G)
GND: C18.1, IC4.2 (V-), R9.2; also elsewhere on the board
unnamed: R6.2, VTL1.1 (A)
unnamed: R2.2, VD2.C
unnamed: IC1.6 (OUT), IC1.7 (OUT), R1.2, VD2.A
unnamed: R1.1, R2.1, VT1.1 (G)
unnamed: C11.1, R3.2
unnamed: IC2.6 (OUT), IC2.7 (OUT), R23.2
unnamed: R23.1, VT5.1 (G)
unnamed: L2.1, VD3.C, VT5.3 (D)
unnamed: C24.+, COOLER.2, L2.2, R24.1
unnamed: R14.2, R15.2, VT2.1 (G)
unnamed: IC4.1 (+IN), R18.1
unnamed: C19.1, R16.2
unnamed: DVT1.C, R5.2, VTL1.3 (EMIT)
unnamed: DVT1.B, VTL1.4 (COL)
unnamed: C19.2, IC4.3 (-IN), R9.1, R17.1
PA16(COOL): IC2.2 (IN), R22.1; also elsewhere on the board
PA17(/SW): VTL1.2 (C); also elsewhere on the board
PA18(/OUT): IC1.2 (IN); also elsewhere on the board
PL: C12.+, C13.+, C14.+, C15.1, C16.1, C17.1, L1.1, L1.1@2 (1), PL.1, PL2.1, VD10.C, VT2.2 (D)
PL1: PL1.1, VT3.5 (D), VT3.6 (D), VT3.7 (D), VT3.8 (D)
S_VT2: R10.2, R11.2, R12.2, R13.2, R14.1, VT2.3 (S)
UDAC: IC4.4 (OUT), R15.1, R16.1, R17.2

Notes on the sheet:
micD21.v5X
R10...R13
R7,R8
OlMoro 2022

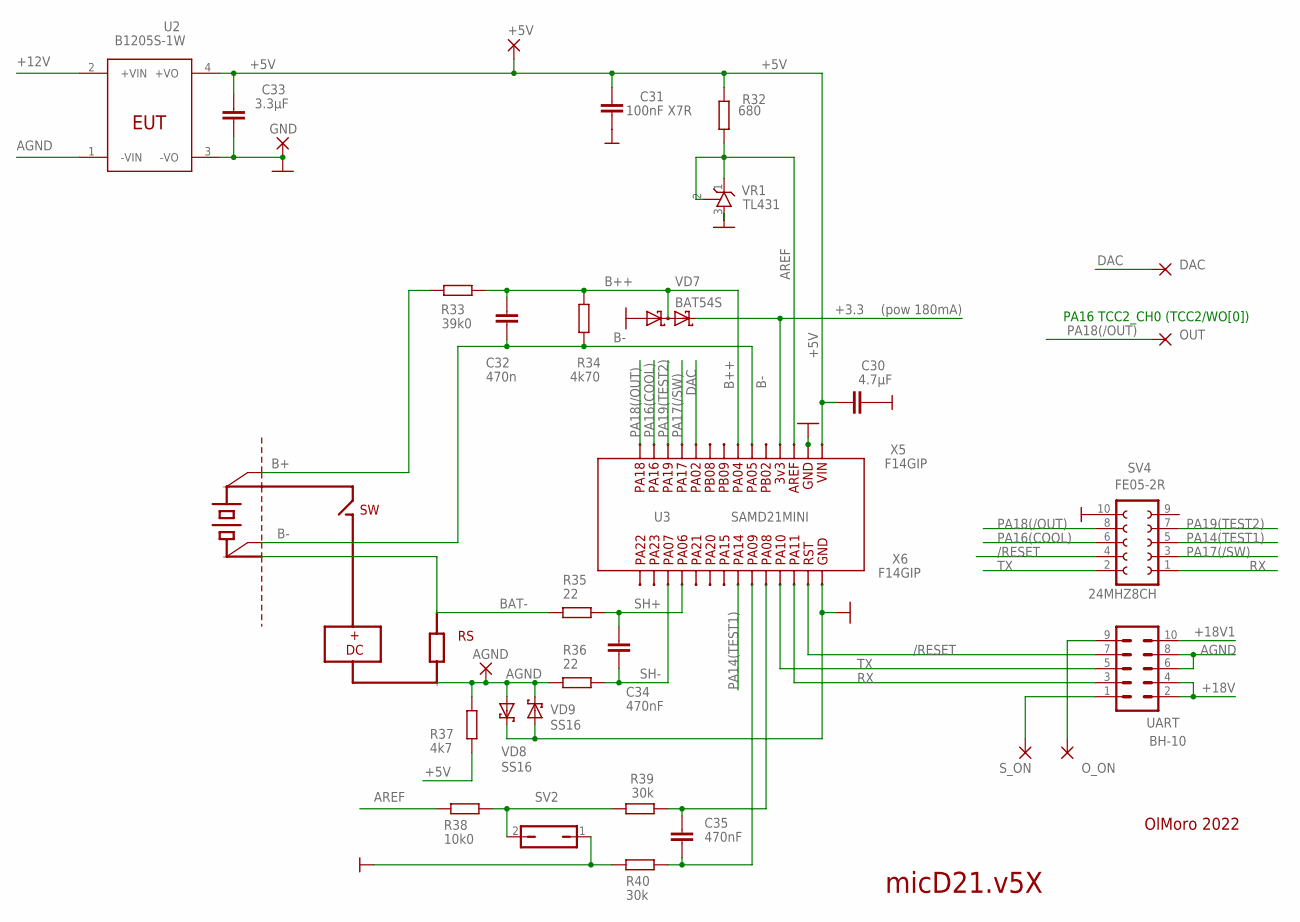
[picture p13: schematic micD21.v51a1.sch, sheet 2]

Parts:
24MHZ8CH: DIAGNOSTICS
+5V: 1,6/0,8
AGND: AGND; 4,16O1,6
C30: 4.7µF; C0805
C31: 100nF X7R; C0603
C32: 470n; C0603
C33: 3.3µF; C0805
C34: 470nF; C0603
C35: 470nF; C0805
DAC: 1,6/0,8
GND: GND; 4,16O1,6
OUT: 1,6/0,8
O_ON: 1,6/0,8
R32: 680; R0603
R33: 39k0; R0603
R34: 4k70; R0603
R35, R36: 22; R0603
R37: 4k7; R0603
R38: 10k0; R0603
R39, R40: 30k; R0603
SV2: JP1Q; JP1
SV4: FE05-2R
S_ON: 1,6/0,8
U2: B1205S-1W; HLK-1D1212
U3: SAMD21MINI
UART: BH-10; ML10
VD7: BAT54S; SOT23
VD8, VD9: SS16; DO214AC
VR1: TL431; SOT23
X5, X6: F14GIP

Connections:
+3.3: VD7.2 (C2), X5.4; also elsewhere on the board
+5V: +5V.1, C30.1, C31.1, C33.1, R32.1, R37.2, U2.4 (+VO), X5.1; also elsewhere on the board
+12V: U2.2 (+VIN); also elsewhere on the board
+18V: UART.2, UART.4; also elsewhere on the board
+18V1: UART.10; also elsewhere on the board
/OUT_ON: O_ON.1, UART.9
/RESET: SV4.4, UART.7, X6.13
/S_ON: S_ON.1, UART.1
AGND: AGND.1, R36.2, R37.1, U2.1 (-VIN), UART.6, UART.8, VD8.A, VD9.C; also elsewhere on the board
AREF: R32.2, R38.1, VR1.1 (C), VR1.2 (R), X5.3
B+: R33.2; also elsewhere on the board
B++: C32.1, R33.1, R34.1, VD7.3 (C1A2), X5.7
B-: C32.2, R34.2, X5.6; also elsewhere on the board
BAT-: R35.2; also elsewhere on the board
CELSIUS: C35.1, R39.2, X6.10
DAC: DAC.1, X5.10; also elsewhere on the board
GND: C30.2, C31.2, C33.2, GND.1, R40.1, SV2.1, SV4.10, U2.3 (-VO), VD7.1 (A1), VD8.C, VD9.A, VR1.3 (A), X5.2, X6.14; also elsewhere on the board
unnamed: C35.2, R40.2, X6.9
unnamed: R38.2, R39.1, SV2.2
PA14(TEST1): SV4.5, X6.8
PA16(COOL): SV4.6, X5.13; also elsewhere on the board
PA17(/SW): SV4.3, X5.11; also elsewhere on the board
PA18(/OUT): OUT.1, SV4.8, X5.14; also elsewhere on the board
PA19(TEST2): SV4.7, X5.12
RX: SV4.1, UART.3, X6.12
SH+: C34.1, R35.1, X6.4
SH-: C34.2, R36.1, X6.3
TX: SV4.2, UART.5, X6.11

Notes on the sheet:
micD21.v5X
+ DC
PA16 TCC2_CH0 (TCC2/WO[0])
(pow 180mA)
OlMoro 2022

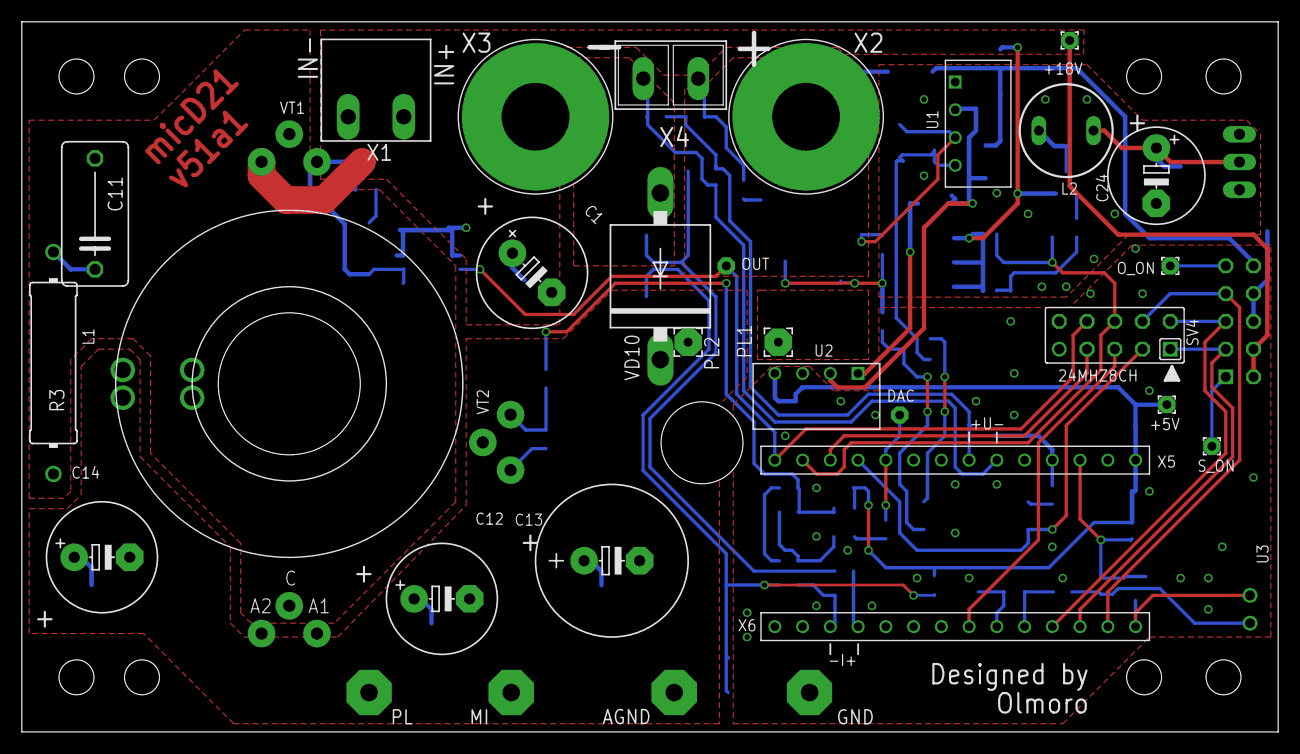
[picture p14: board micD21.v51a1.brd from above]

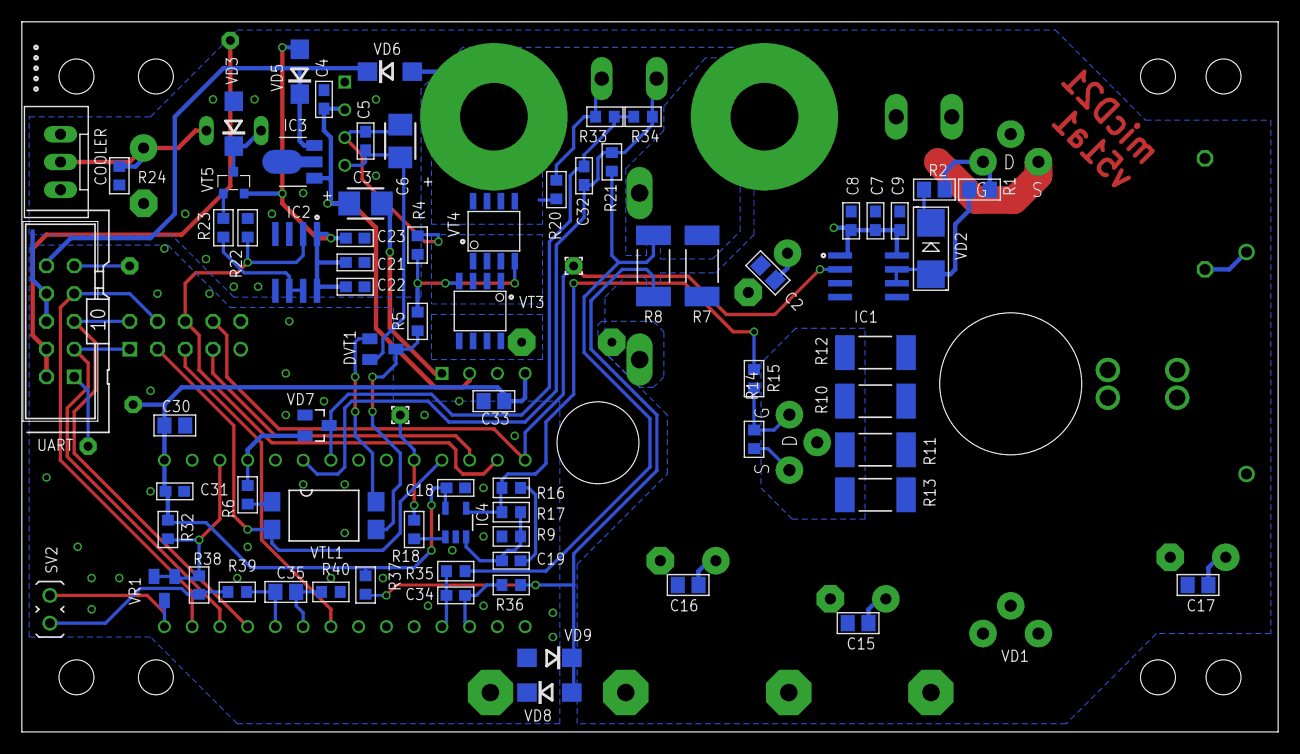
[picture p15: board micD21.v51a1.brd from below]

Board: 2 copper layers, 115.0 x 65.0 mm, 110 parts (77 on the bottom side), 52 nets.

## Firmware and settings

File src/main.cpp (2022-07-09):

/*
  https://manualzz.com/doc/11587480/using-atsamd21-sercom-for-more-spi--i2c-and-serial-ports
  Using ATSAMD21 SERCOM for more SPI, I2C and Serial ports

  View detail for Atmel AT11628: SAM D21 SERCOM I2C Configuration

  Вариант с UART
  03 июль 2022  v0.1
  Platform: 7.1.0
  VS: 1.65.0  -> 1.67.0 -> 1.67.2
  pcb: micD21.v51 -> .v53
*/

#include "board/mpins.h"
#include "wake/wake.h"
#include "commands/commands.h"
#include "power/power_reg.h"
#include "adc/adc.h"
    //#include "power/power_pwm.h"
    #include "power/mpwm.h"

#include <Arduino.h>            // N. порядок не нарушать!
#include "wiring_private.h"     // N=1.


void setup() 
{
  // инициализация UART порта обмена с ESP32 ( D0:PA11/UART-RX, D1:PA10/UART-TX )
  Serial1.begin(230400);            // Проверено
  while(!Serial1);

  portsInit();
  wakeInit(0x00, 5);                // обмен без адреса, время ожидания 5 ms
//initAdc(0);                       // не обязательно
  initMeasure();
  initPids();                       // 
  initState1();
  initState2();
}

void loop() 
{
    // Измерения и регулирование
    // считать, преобразовать, задать следующее и запустить
  measure();

    // Если в буфере приема есть принятые байты (не факт, что пакет полный), 
    // пока не принят весь пакет, время ожидания ограничено (пока 1с).   
  if(Serial1.available()) {wakeRead();}

  doState1();
  doState2();
  doCommand();                  // Если ненулевая, будет исполнена.
}

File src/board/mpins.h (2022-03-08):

#ifndef _MPINS_H_
#define _MPINS_H_
/*
* https://github.com/BLavery/SAMD21-M0-Mini
* select the board: Tools/Board = Arduino SAMD / "Arduino Zero (Native USB Port)".
* Double-click the board reset button. Upload. See if a LED blinks.
* explain a bit:
* 1. The Arduino bootloader uses double click on reset button to enter flash upload mode. Single
*    reset enters normal running mode. (Boot0/1 jumpers, like STM32 uses, are not used on the SAMD.)
* 2. The serial/bossac mode of USB upload is included in the Arduino install.
* 3. The regular user LED is missing. So we choose one of the TX/RX LEDs. For the moment, 
*    the Arduino sketch is NOT otherwise driving these as TX/RX indicators (see above), 
*    so we can re-employ them.
* 4. But what pin or GPIO number? For this board, reference the pins as 0-26 or A0-A5. Not D25, 
*    nor PB03 or PB3.
*
* https://github.com/arduino/ArduinoCore-samd/pull/374/files
* additional analog inputs: A6-A11 #374 
*
* Версия от 05 марта 2022г. 
* pcb: micD21.v51 с исправлениями (PA15, PA16, PA18)
*/

#include "stdint.h"

namespace MPins
{
//                  name        arduino_pin  M0-MINI   SAMD21_name
// A0 PA02 - аналоговый выход на цепь разряда
constexpr uint8_t dac_pin           =   14;    // A0   PA02

// A3 PA04 - плюсовой вход измерителя напряжения на нагрузке
constexpr uint8_t bat_plus_pin      =   17;    // A3   PA04
constexpr uint8_t bat_plus_mux      =    4;    // A3   PA04

// A4 PA05 - минусовой вход измерителя напряжения на нагрузке
constexpr uint8_t bat_minus_pin     =   18;    // A4   PA05
constexpr uint8_t bat_minus_mux     =    5;    // A4   PA05

// D8 PA06 - плюсовой вход измерителя тока
constexpr uint8_t shunt_plus_pin    =   46;    // D8   additional analog as PA06
constexpr uint8_t shunt_plus_mux    =    6;    // D8   additional analog as PA06

// D9 PA07 - минусовой вход измерителя тока
constexpr uint8_t shunt_minus_pin   =   47;    // D9   additional analog as PA07
constexpr uint8_t shunt_minus_mux   =    7;    // D9   additional analog as PA07

// D2 PA08 - плюсовой вход измерителя напряжения источника или температуры (резерв)
constexpr uint8_t pow_plus_pin      =   51;    // D2   additional analog as PA08
constexpr uint8_t pow_plus_mux      =    8;    // D2   additional analog as PA08

// D3 PA09 - минусовой вход измерителя напряжения источника (резерв)
constexpr uint8_t pow_minus_pin     =   50;    // D3   additional analog as PA09
constexpr uint8_t pow_minus_mux     =    9;    // D3   additional analog as PA09

// D0/D1 PA11/PA10 - SERCOM/UART (Serial1, обмен с ESP32)                                         Logic Analyzer Inputs v.51
constexpr uint8_t uart_rx           =    0;    // D0   PA11/UART-RX                                       Ch 0
constexpr uint8_t uart_tx           =    1;    // D1   PA10/UART-TX                                       Ch 1
constexpr uint8_t sw_pin            =   13;    // D13  PA17 Управление силовыми ключами (нагрузкой)       Ch 2
                                               //      /reset                                             Ch 3
constexpr uint8_t test1             =    2;    // D4   PA14 Тестовый вывод для осциллографирования        Ch 4
constexpr uint8_t cool_pin          =   11;    // D11  PA16 ШИМ на вентилятор                             Ch 5
constexpr uint8_t test2             =   12;    // D12  PA19 Тестовый вывод для осциллографирования        Ch 6
constexpr uint8_t out_pin           =   10;    // D10  PA18 ШИМ на силовой преобразователь                Ch 7

// PB10, PB11, PA12, PA13 - не используются (нет на SAMD21 MINI)
// PB03, PA27 - только на SMD21 MINI

constexpr uint8_t led_rx            =   25;    // no   PB03/LED1 (LED_BUILTIN, LED_RX)
constexpr uint8_t led_tx            =   26;    // no   PA27/LED2 (LED_TX)

// PB02, PB03, PB08, PB09 - не используются (нет на младших)
};

#endif // !_MPINS_H_

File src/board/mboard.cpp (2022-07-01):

/*
  
 * Версия от 23 октября 2020г.
*/

#include "board/mboard.h"
#include "board/mpins.h"
#include "adc/adc.h"    // DAC
#include <Arduino.h>

  // state1 - состояния, true - включено:
extern bool switchStatus;         // коммутатор нагрузки ( sw_pin   )
extern bool powerStatus;          // преобразователь     (  )
// extern bool currentControlStatus;  // регулирование по току
extern bool voltageControlStatus;  // регулирование по напряжению
extern bool chargeStatus;         // заряд               (  )
extern bool dischargeStatus;      // разряд (тот же вывод, !chargeStatus )
// extern bool pauseStatus;           // пауза
extern bool pidStatus;             // pid-управление регулятором

  // Включение силовых ключей
void swPinOn()
{
  digitalWrite( MPins::sw_pin, LOW );
  switchStatus = true;
}

  // Выключение силовых ключей
void swPinOff()
{
  digitalWrite( MPins::sw_pin, HIGH );
  switchStatus = false;
}

void test1On()  { digitalWrite( MPins::test1, LOW  ); }  // Включение тестового вывода
void test1Off() { digitalWrite( MPins::test1, HIGH ); }  // Отключение  тестового вывода

void test2Low()  { digitalWrite( MPins::test2, LOW  ); }  // Включение тестового вывода
void test2High() { digitalWrite( MPins::test2, HIGH ); }  // Отключение  тестового вывода


  // Инициализация дискретных портов
void portsInit()
{
  pinMode( MPins::test1,  OUTPUT);  
  pinMode( MPins::test2,  OUTPUT);
  pinMode( MPins::sw_pin, OUTPUT);
   
  #ifdef WEMOS    // using pcb SAMD21 MINI
    pinMode( MPins::led_rx, OUTPUT);  // led_rx   = 25   no   PB03/LED1 (LED_BUILTIN, LED_RX)
    pinMode( MPins::led_tx, OUTPUT);  // led_tx   = 26   no   PA27/LED2 (LED_TX)
  #endif

  swPinOff();               // Силовые ключи нагрузки отключены
  test1Off();
  test2Low();               //
  dacInit();                // Set reference
  dacWrite10bit( 0x0000 );  //
}

  // Конфигурация режимов
void configMode(uint8_t mode)
{
  switch ( mode )
  {
  case 1:                             // U - регулирование по напряжению
    //chargeStatus = true;              // коммутатор на заряд
    //dischargeStatus = !chargeStatus;
    powerStatus = true;               // преобразователь включить
//    powPinOn();
    switchStatus = true;              // к клеммам подключить
    swPinOn();
  break;

  case 2:                             // I - регулирование по току заряда
    //chargeStatus = true;              // коммутатор на заряд
    //dischargeStatus = !chargeStatus;
    powerStatus = true;               // преобразователь включить
//    powPinOn();
    switchStatus = true;              // к клеммам подключить
    swPinOn();
  break;

  case 3:                             // D - регулирование по току разряда
    //dischargeStatus = true;           // коммутатор на заряд
    //chargeStatus = !dischargeStatus;
    powerStatus = false;              // преобразователь выключить
//    powPinOff();
    switchStatus = true;              // к клеммам подключить
    swPinOn();
  break;

  default:    // OFF
    //chargeStatus = true;              // коммутатор на заряд
    //dischargeStatus = !chargeStatus;
    powerStatus = false;              // преобразователь выключить
//    powPinOff();
    switchStatus = false;             // от клемм отключить
    swPinOff();
  break;
  }
}

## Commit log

2022-02-19 History PWM tab
2022-03-08 PWMs to PA16, PA18
    Для совместимости с выбранной библиотекой Turbo_PWM
2022-03-08 pwm optimization
2022-03-15 power test
2022-03-24 эксперименты с шим
2022-04-21 test 9V 1A
2022-04-23 v51a1 sch
    [micD21.v51a1.brd, micD21.v51a1.sch]
2022-04-28 pcb v52 added
    [mcdm.v52.brd, mcdm.v52.sch, micD21.v51a1.brd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]
2022-05-03 PCB_v53 added
    [mcdm.v52.brd, mcdm.v52.sch]
2022-05-05 pwm cool
2022-05-07 pwm optim
2022-05-24 test pwm
2022-05-26 test PID
2022-05-27 Калибровки
2022-06-07 New PowerStop (0x21)
2022-06-14 pid test
2022-06-17 Test pid U, I
2022-06-21 Настройки ПИД
2022-06-22 ПИД тест
2022-07-01 пид множитель 12бит

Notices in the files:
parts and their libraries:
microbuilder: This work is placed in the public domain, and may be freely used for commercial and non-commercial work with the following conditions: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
